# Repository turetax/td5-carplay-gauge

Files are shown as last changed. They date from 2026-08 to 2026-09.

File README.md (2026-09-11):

# TD5 CarPlay Gauge

A Raspberry Pi-based infotainment system with real-time engine monitoring and
Apple CarPlay for Land Rover Defender and Discovery 2 models powered by the
2.5-litre, five-cylinder TD5 diesel engine.

This is an independent hobby/diagnostic project. It is not affiliated with or
endorsed by JLR, Land Rover, Apple, Google, Spotify, or other trademark owners.

The TD5 dashboard is integrated directly into LIVI and runs as part of the same
full-width vehicle interface as CarPlay. Engine data is read from the TD5 ECU
through a K+DCAN cable and presented in a touch-friendly dashboard built for the
project's 1920 × 440 display.

## Features

* Live TD5 engine data inside the LIVI interface
* Apple CarPlay integration through LIVI, intended for use with a Carlinkit adapter
* A Defender-style idle dashboard with a clock, vehicle silhouette, session status,
  and live engine values whenever CarPlay is not streaming
* Coolant temperature, engine speed, voltage, fuel temperature, intake air
  temperature, MAP, calculated boost, MAF, wastegate, throttle, and injector
  balance readings
* Session peaks, trends, local history, and alert history
* Read-only ECU fault-code retrieval
* Visual warnings and an audible high-coolant-temperature alarm
* Automatic reconnection when the K+DCAN cable or ECU becomes available
* Touch-optimized interface for an in-vehicle ultra-wide display

## How it works

The system consists of two cooperating processes on the Raspberry Pi:

1. The Python TD5 gateway communicates with the ECU through `/dev/ttyUSB0`. It
   performs the TD5 diagnostic login, continuously reads engine values, and
   exposes them through a local API at `http://127.0.0.1:8080`.
2. LIVI runs as the single full-screen vehicle interface. Its built-in TD5 page
   reads the local gateway API and displays live values, history, warnings, and
   diagnostic information. LIVI also manages the CarPlay projection session. When
   the phone is disconnected, the projection area automatically becomes a compact
   vehicle overview; an active CarPlay video stream replaces it immediately.

The gateway and dashboard are read-oriented. Fault-code requests only read stored
and active faults; they do not clear codes, change ECU settings, or perform actuator
commands.

On the reference Pi, the TD5 gateway has exactly one boot entry: the desktop
user's `@reboot` cron entry. Do not additionally enable the optional systemd
gateway unit on that Pi, since two copies cannot share the local API port.

### Diagnostic architecture

The gateway is deliberately separated into a TD5 protocol layer and a small
serial transport layer. `td5_transport.py` owns adapter timing and fast init;
`td5gauge.py` owns the read-only TD5 request/decoder flow; and
`td5_signals.py` is the machine-readable catalogue of confirmed display values.
The default K-line wake-up method remains `break-condition`, which is the method
tested with this project. A `send-break` alternative is available only as an
explicit configuration choice for adapter-specific Linux testing; it is not a
general recommendation and must be verified on the vehicle first.

## Hardware

The current installation uses:

* A Raspberry Pi 4 Model B running Raspberry Pi OS
* An 11.26-inch touchscreen (1920 × 440) with an IPS panel, HDMI video input,
  and USB touch input
* A K+DCAN USB cable with an FTDI-compatible serial interface and K-line connected
  to OBD pin 7
* A Carlinkit CPC200-CCPA USB adapter for wired or wireless Apple CarPlay. The
  adapter has been purchased but has not yet arrived, so this hardware combination
  has not yet been tested in the project.

The touchscreen is detected as an ILITEK USB device and mapped to the HDMI output
by the included Wayland configuration.

### Display installation

A complete guide for installing the display in the vehicle will be added later.
It will cover physical mounting, bracket design, cable routing, dashboard fitment,
and the final in-vehicle connections. Until that guide and the power solution have
been completed and tested, the display should be treated as a bench-tested part of
the project rather than a ready-to-install vehicle kit.

### Vehicle power solution

The vehicle power solution has not yet been finalized. Work is ongoing on a safe
and reliable way to power the Raspberry Pi, display, and connected USB devices in
the vehicle.

> **Warning:** Do not connect the Raspberry Pi, display, or USB hardware directly
> to the vehicle's 12 V electrical system. These devices require properly regulated
> power, and a direct connection can permanently damage the equipment, overheat
> wiring, or create a fire risk.

A vehicle electrical system is not a clean, constant 12 V supply. Its voltage can
drop during engine cranking and rise significantly during charging or electrical
transients. The final solution therefore needs an automotive-rated DC-DC converter,
appropriate input protection, a fuse installed close to the power source, correctly
rated wiring, and sufficient output capacity for the complete system.

The power controller must also monitor the ignition state. When the ignition is
switched off, it should keep the Raspberry Pi powered long enough to complete an
orderly shutdown before disconnecting power. Cutting power immediately can corrupt
the filesystem or SD card and may prevent the system from starting correctly the
next time. Until a tested power solution is documented, this project should only be
powered from a suitable protected and regulated bench supply during testing.

### CarPlay hardware status

LIVI provides the software integration for CarPlay, but the planned Carlinkit
CPC200-CCPA dongle has not yet been connected or verified with this installation.
CarPlay support should therefore be considered untested until the adapter arrives
and has been validated on the Raspberry Pi.

## Raspberry Pi installation

Start with a fresh Raspberry Pi OS installation with the desktop, a network
connection during installation, and a supported touchscreen. Use a dedicated Pi
and SD card: this installer configures the desktop user to start the vehicle
interface automatically.

1. Flash Raspberry Pi OS (64-bit, desktop) using Raspberry Pi Imager. Create a
   normal user and enable Wi-Fi or Ethernet for the initial installation.
2. On the Pi, clone this repository and initialize the included LIVI source:

   ```sh
   git clone --recurse-submodules REPOSITORY_URL td5-carplay-gauge
   cd td5-carplay-gauge
   ```

3. Run the installer as that normal desktop user. It asks for the administrator
   password only to install packages and register the gateway service:

   ```sh
   ./scripts/install-pi.sh
   ```

4. If Node.js and `pnpm` are already installed, add `--build-livi` to build the
   integrated Td5/LIVI interface in the same step. Otherwise follow LIVI's
   documented Raspberry Pi build prerequisites, then run:

   ```sh
   ./scripts/install-pi.sh --build-livi
   ```

   For the production AppImage (preferred for the installed head unit), use:

   ```sh
   ./scripts/install-pi.sh --package-livi
   ```

   The launcher automatically prefers that package and falls back to the
   source-built Electron app when no package is present.

5. Restart the Pi. The gateway starts at boot and the full-screen dashboard is
   registered as a desktop autostart application. Connect the K+DCAN cable,
   turn the ignition to position II, and wait for the ECU state in the footer.

The installer deliberately defaults to the local-only API and read-only ECU
operations. It does not clear faults, change ECU configuration, or actuate ABS
components. Verify the wiring and software after installation with:

```sh
~/td5gauge/scripts/td5-health-check.sh
```

### First-boot configuration

`/etc/td5-gauge.conf` is created on the Pi. Normally it needs no changes: the
startup script prefers the stable `/dev/serial/by-id/...` identity of the first
USB serial adapter and only falls back to `/dev/ttyUSB0`. If several serial
adapters are connected, set the exact path in that file, then restart the
gateway:

```sh
sudo systemctl restart td5-gateway.service
```

For a production-quality kit, distribute a tested SD-card image containing the
already-built LIVI bundle. That avoids compiling Node/Electron on the buyer's
Pi and makes the above first boot genuinely flash-card, connect, and drive.

## Manual source setup

Clone the repository and enter the project directory:

```sh
git clone REPOSITORY_URL td5-carplay-gauge
cd td5-carplay-gauge
git submodule update --init
```

Create a Python virtual environment and install the TD5 gateway dependency:

```sh
python3 -m venv .venv
source .venv/bin/activate
python3 -m pip install -r requirements.txt
```

Replace `REPOSITORY_URL` with the HTTPS or SSH clone URL shown on the repository's
GitHub page. No fixed username or local installation path is required.

Apply the TD5 interface changes to the pinned LIVI source:

```sh
./scripts/apply-livi-patch.sh
```

The automated installer above is the recommended setup for a Raspberry Pi. More
detailed documentation for manual package installation, startup configuration,
display setup, and physical vehicle installation will be added as the hardware
setup is finalized.

## Runtime

For a manual or temporary test, start the TD5 gateway with:

```sh
python3 td5gauge.py --port /dev/ttyUSB0
```

The gateway keeps retrying until both the USB adapter and TD5 ECU are available.
It listens only on `127.0.0.1` by default because the API is intended for the TD5
page inside LIVI. Do not expose the diagnostic API to an untrusted network.
The installed system starts the gateway through `td5-gateway.service` and launches
the integrated LIVI interface through the desktop autostart entry installed by
`scripts/install-pi.sh`.

Boot timing markers for both processes are included in the health check:

```sh
~/td5gauge/scripts/td5-health-check.sh
```

To try the dashboard without a connected vehicle or K+DCAN cable, start it with
simulated TD5 data:

```sh
python3 td5gauge.py --simulate
```

## Roadmap

The project is currently focused on read-only diagnostics. Planned future work
includes:

* Adding carefully controlled ECU write operations
* Clearing diagnostic trouble codes from the TD5 ECU
* Supporting the ABS bleed procedure through the diagnostic interface
* Integrating a reversing camera into the LIVI interface
* Developing the vehicle power solution, including ignition-state detection and a
  controlled shutdown sequence so the Raspberry Pi can shut down safely before
  power is removed
* Publishing complete instructions for mounting and connecting the ultra-wide
  display in the vehicle

ECU write operations and ABS service procedures are safety-critical features.
They will require validated protocol support, clear user confirmation, appropriate
interlocks, and testing on compatible hardware before being enabled for general
use.

## Important

* This is not generic OBD-II. The TD5 uses its own diagnostic login and command
  flow.
* K+DCAN cables vary. OBD pin 7 must be electrically connected to K-line, and the
  USB chipset must expose a serial port.
* Never run multiple diagnostic applications against the same ECU connection.
* Disconnect the K+DCAN cable before using workshop diagnostic equipment.
* Do not use the displayed values as the sole basis for safety-critical decisions
  while driving.
* Keep Wi-Fi names, passwords, SSH keys, diagnostic profiles, and vehicle logs out
  of Git. `.env.example` documents the optional Wi-Fi variables.

## LIVI source dependency

`third_party/LIVI` is an upstream Git repository. Publish it as a pinned
submodule/fork and retain the Td5 changes as a patch or a commit in that fork;
do not publish an uncommitted nested working tree. This repository includes
`patches/livi-td5-gauge.patch`, generated against the revision recorded in
`third_party/LIVI.UPSTREAM_REVISION`. After cloning, initialize the submodule and
run `scripts/apply-livi-patch.sh` before building LIVI.

## Projects this work builds upon

* [BinOwl TD5 Gauge](https://github.com/k0sci3j/BinOwl_Td5Gauge) provides the
  foundation for the TD5 diagnostic protocol, login sequence, and command
  structure.
* [LIVI – Linux In-Vehicle Infotainment](https://github.com/f-io/LIVI) provides
  the Raspberry Pi infotainment and CarPlay platform into which the TD5 dashboard
  is integrated.

Many thanks to these projects and their contributors.

## License

This project contains a derivative port of the TD5 diagnostic command flow from
the BinOwl TD5 Gauge firmware and is distributed under
[GPL-3.0-or-later](COPYING). Refer to the upstream projects for their respective
license terms and attribution requirements.

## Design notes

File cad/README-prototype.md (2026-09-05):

# Defender EP-0189 prototype

This is a provisional fit prototype, not a final road-ready mount.

Assumptions:

- GeeekPi EP-0189 body: 276.29 x 76.50 mm (official, ±0.1 mm).
- Official viewing area: 252.69 x 57.90 mm (±0.1 mm).
- Depth remains provisional at 15 mm.
- Outer corner radius is not published; V2 uses an image-scaled estimate of
  R6.5 mm. Confirm this on the physical unit before a final print.
- Screen clearance: 0.6 mm total.
- Central rear tunnel: 198 x 70 x 62 mm, based on the published usable
  MUD-0039 face size. This is not a verified copy of its fixing geometry.
- Screen is loaded from the rear. The front lip overlaps the assumed screen
  envelope by 1 mm on every edge.
- Rear tunnel is deliberately open for cable routing and test fitting.
- The rear fixing rail has two 5.2 mm high horizontal M4 trial slots. Together
  they cover symmetric screw centre spacings from 130 to 210 mm. This is an
  intentionally adjustable test pattern, not a claimed factory dimension.

Print `ep0189_fit_coupon.stl` first. It checks the assumed screen width,
height and depth with much less material. Do not force the screen into it.

Print `defender_mount_slot_template.stl` to test the dashboard fixing centres
without printing the full housing. The template is 220 x 22 x 3 mm. Hold it
against the rear fixing points, centre it, and note the distance between the
two screw centres and their vertical offset relative to the radio opening.

The full concept housing is 284.6 x 84.6 x 81.2 mm. It may need to be split
in the slicer for printers with a bed smaller than 285 mm. Print the front
face on the bed. Use a draft profile for the first vehicle test.

The model does not yet include verified Defender screw holes, Pi standoffs,
connector cut-outs, ventilation, relay/fuse mounts or a rear service cover.
Those should be added after checking the physical screen and dashboard fit.

`defender_ep0189_one_piece_reference_fit.stl` is the preferred combined test.
It replaces the guessed slotted rail with the actual `Binnacle_Vent_Rail_v1.1`
mesh from Thingiverse design 5856588, centred and overlapped with the housing
by 0.8 mm so a slicer treats it as one part. The reference was designed and
test-fitted by mbrooker for a pre-Td5 Defender and is licensed CC BY 4.0:
https://www.thingiverse.com/thing:5856588

This reuse improves the dashboard-facing geometry, but does not prove fit in
every 1998 vehicle. The GeeekPi portion is still based on approximate published
dimensions and requires a physical fit check.

`defender_ep0189_v4_flush_one_piece.stl` places the screen's own front surface
in the same plane as the housing front. No printed bezel overlaps the screen.
The screen loads from the front and stops against a 1.2 mm rear perimeter lip.
This lip position assumes a 15 mm screen depth and must be checked physically.

To regenerate after editing the constants:

```sh
python3 cad/generate_defender_screen_prototype.py
```

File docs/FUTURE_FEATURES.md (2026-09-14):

# Framtida funktioner och återstående arbete

Den här listan sammanför projektets roadmap, nästa live-test, LIVI:s
telemetriplan och återstående arbete på den fysiska installationen. Punkter som
redan är delvis implementerade är markerade så att listan inte blandar ihop
färdig funktionalitet med återstående verifiering.

## Prioriterad arbetsordning

1. Stabil strömförsörjning utan underspänning eller strypning.
2. Komplett fordonstest med K+DCAN och TD5 ECU.
3. Verifiering och avkodning av injektorkoder.
4. CarPlay-test med riktig Carlinkit CPC200-CCPA.
5. Färdig kapsling och fordonsmontering.
6. Säkerhetskritiska ECU- och ABS-funktioner.

## TD5-diagnostik

### Nästa live-test

- Verifiera att gatewayen hittar K+DCAN via `/dev/serial/by-id`.
- Kontrollera RPM, kylvätska, laddspänning, MAP, MAF och bränsletemperatur mot
  rimliga värden med motorn igång.
- Långtidstesta anslutningen utan återanslutningar.
- Behåll `break-condition`; prova `send-break` bara vid återkommande problem och
  dokumentera kabelns USB-krets.
- Verifiera manuell, skrivskyddad DTC-avläsning i bilen.

### Injektorkoder — högsta diagnostikprioritet

- Läs ett enda skrivskyddat `21 3D`-konfigurationsblock.
- Kontrollera svarslängd, svarstyp och kontrollsumma.
- Jämför råsvaret med de fem fysiska spridarkoderna och aktuell ECU/motorkarta.
- Visa injektor 1–5 med kod och idle-nummer först efter entydig verifiering.
- Visa aldrig gissade injektorkoder.

### Säkerhetskritiska senare funktioner

- Radera TD5-felkoder.
- Skriva injektorkoder och andra ECU-inställningar.
- Eventuell immobiliseringshantering.
- ABS-luftning.
- ABS-pump-, ventil- och andra aktuatorprov.
- Kräv validerat protokoll, stillastående fordon, tydlig bekräftelse,
  säkerhetsspärrar och test på kompatibel Defender innan aktivering.

## CarPlay, Android Auto och telemetri

### CarPlay-test på riktig hårdvara

Status 2026-09-13: CPC200-CCPA är inkopplad och identifierad som `1314:1521
Magic Communication Tec. Auto Box`. LIVI har etablerat länken och visar
1174 × 440 H.264-video med Raspberry Pi:s hårdvaruavkodare och DMA-buffert.
Punkterna nedan som kräver handpåläggning återstår.

- USB-detektering och första videolänk är verifierade; långtidstesta stabiliteten.
- Testa trådbunden och trådlös CarPlay.
- Testa videostart, touch, ljud, mikrofon, Siri och ratt-/mediaknappar.
- Testa återanslutning efter urkoppling, telefonbyte, vila och omstart.
- Kontrollera att TD5-vyn återkommer direkt när CarPlay-video avslutas.

### Native CarPlay-telemetri som återstår

- Hastighet, RPM, växel, backsignal och rattvinkel.
- Blinkers, ljus, helljus, varningsblinkers och parkeringsbroms.
- Bränslenivå, förbrukning och EV-batteridata.
- Kylvätske-, olje-, insugs- och växellådstemperatur.
- Batterispänning, barometertryck, MAP, laddtryck, lambda och AFR.
- Vägmätare och trippmätare.

Nattläge, räckvidd, utomhustemperatur och GPS/GNSS är redan kopplade till
native CarPlay.

### Android Auto

- Migrera återstående AV/media-meddelanden från äldre `oaa` till
  `aap_protobuf` (`Setup`, `Config`, `Start` och `Ack`) i fas 2.

## Fordonsström och installation

- Välj fordonsklassad DC/DC-omvandlare dimensionerad för paj, skärm och USB.
- Lägg till säkring nära matningspunkten och skydd mot transienter/startfall.
- Detektera tändningsläge.
- Behåll reservkraft för en kontrollerad avstängning.
- Bryt matningen först när Raspberry Pi verkligen har stängt av.
- Testa uppstart och avstängning vid verklig motorstart.
- Eliminera rapporterad underspänning och aktiv strypning.
- Skapa en färdig, testad SD-kortsavbild för enkel installation.
- Dokumentera montering, kabeldragning och samtliga fordonsanslutningar.

Den manuella avstängningsknappen och visuell avstängningsbekräftelse är
implementerade. Automatisk avstängning från tändningssignal återstår.

## Kapsling och fysisk montering

- Verifiera skärmdjup, hörnradie, passning och skruvcentrum i bilen.
- Lägg till verifierade Defender-skruvhål.
- Lägg till Raspberry Pi-distanser och fästpunkter.
- Lägg till kontakthål, kabelgenomföringar och ventilation.
- Lägg till relä- och säkringsfästen.
- Lägg till bakre servicelucka och slutligt fäste/rem.
- Genomför temperatur-, vibrations- och slutlig passningstest.

## Teknisk skuld

- Flytta navigeringsstatus till Reacts `AppContext`.
- Ersätt direkt DOM-sökning med React-refs.
- Samordna reglerna för dold navigation.
- Ta bort äldre `label`-fält när översättningsnycklar täcker all text.
- Rätta typworkaround i FFT-worker.
- Rätta kvarvarande typfel och föråldrade testmockar.

## Delvis eller helt implementerat

- Backkamerasida och automatisk växling vid backsignal finns; fysisk kamera ska
  fortfarande verifieras.
- Säker manuell avstängning med bekräftelse finns; tändningsstyrd strömbrytning
  saknas.
- Läsning av TD5-felkoder finns; radering saknas.
- Grundläggande ABS-felkodsläsning finns; luftning och aktuatorprov saknas.
- Injektorsida finns; verifierad avkodning av injektorkoder saknas.

## Ursprungliga källor

- `README.md`, avsnitten om hårdvara, ström och roadmap.
- `docs/NEXT_LIVE_TEST.md`.
- `cad/README-prototype.md`.
- `third_party/LIVI/src/main/shared/types/Telemetry.ts`.
- `third_party/LIVI/src/main/services/telemetry/adapters/cpAdapter.ts`.
- `third_party/LIVI/src/main/services/projection/driver/aa/stack/proto/index.ts`.

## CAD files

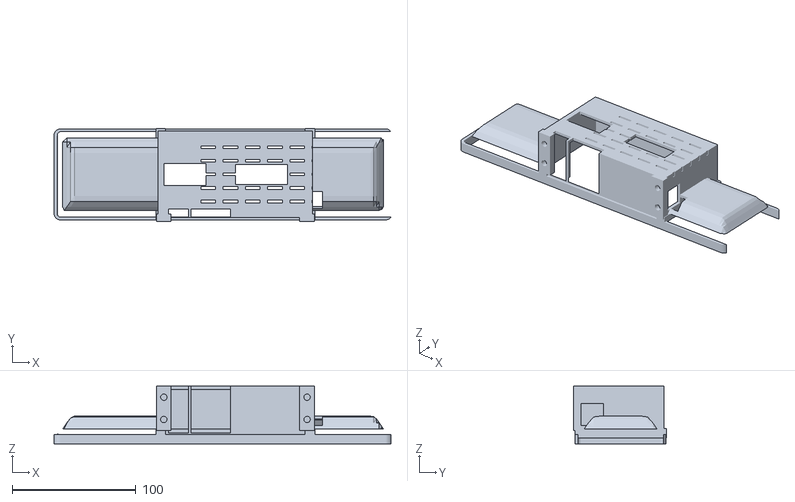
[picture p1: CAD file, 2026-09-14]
3d print/Defender_EP0189_V37_fast90_hoger_gavel_lagad_V44.stl
272.8 x 75.0 x 46.8

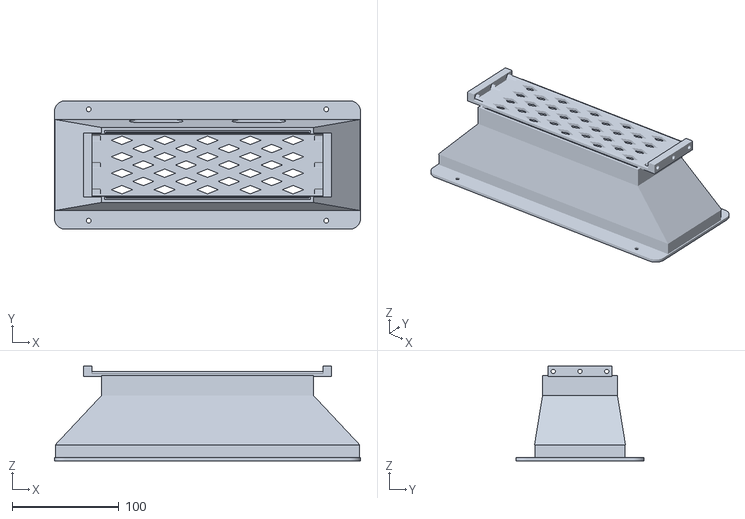
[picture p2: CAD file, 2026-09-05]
3d print/fia/Defender_EP0189_V13_plan_anliggningsyta.stl
286.0 x 120.0 x 88.7

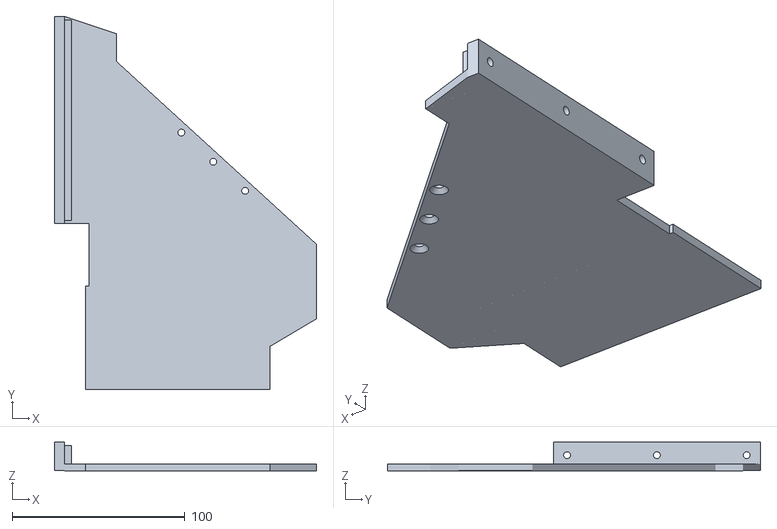
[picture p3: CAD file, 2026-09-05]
cad/reference_thingiverse_5856588/Binnacle_Side_Plate_v1.1_LH.stl
152.0 x 216.0 x 16.5

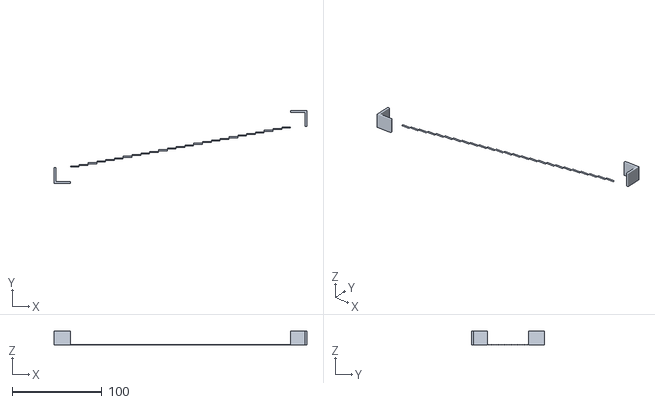
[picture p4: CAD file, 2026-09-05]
cad/stl/ep0189_fit_coupon.stl
281.3 x 81.5 x 15.6

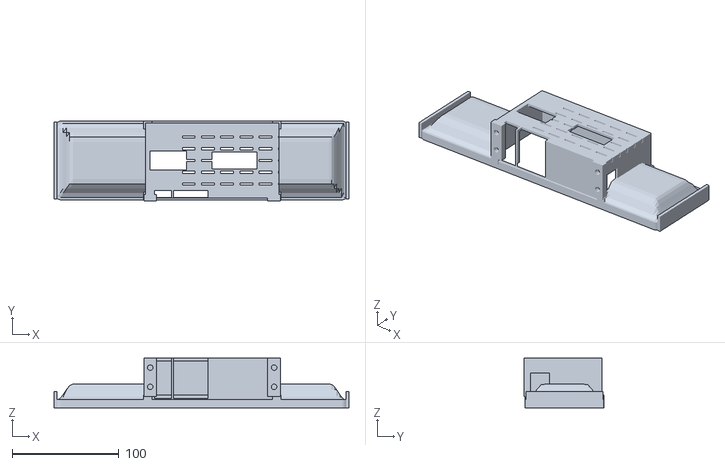
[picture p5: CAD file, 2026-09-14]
3d print/Defender_EP0189_V46_speglad_vanster_gavel_V49.stl
276.2 x 75.0 x 46.8

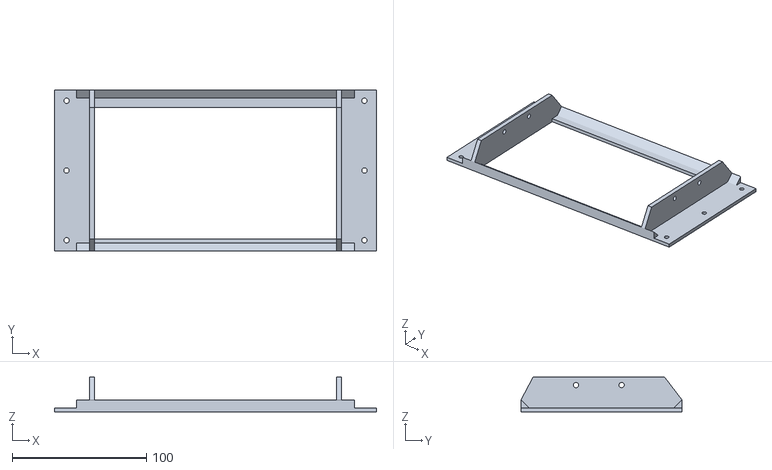
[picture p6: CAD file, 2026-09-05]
cad/reference_thingiverse_5856588/Binacle_Center_Retainer_v1.2.stl
240.0 x 120.0 x 26.0

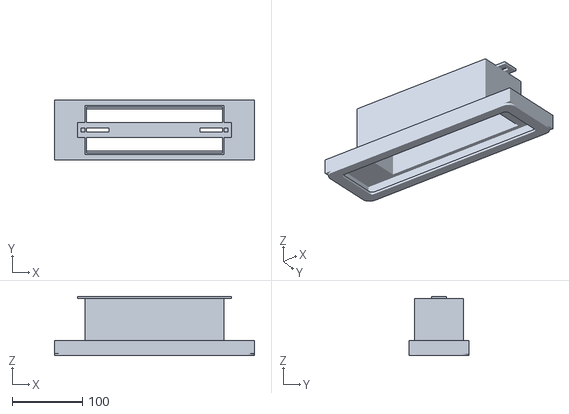
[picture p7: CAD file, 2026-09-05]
cad/stl/defender_ep0189_concept_housing.stl
284.9 x 85.1 x 84.2

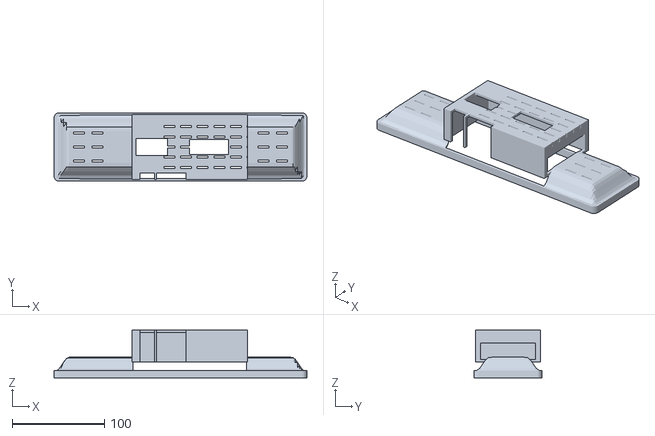
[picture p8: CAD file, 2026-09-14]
3d print/Defender_EP0189_V21_form_plus5mm_flyttade_uttag_V25.stl
273.8 x 73.8 x 51.8

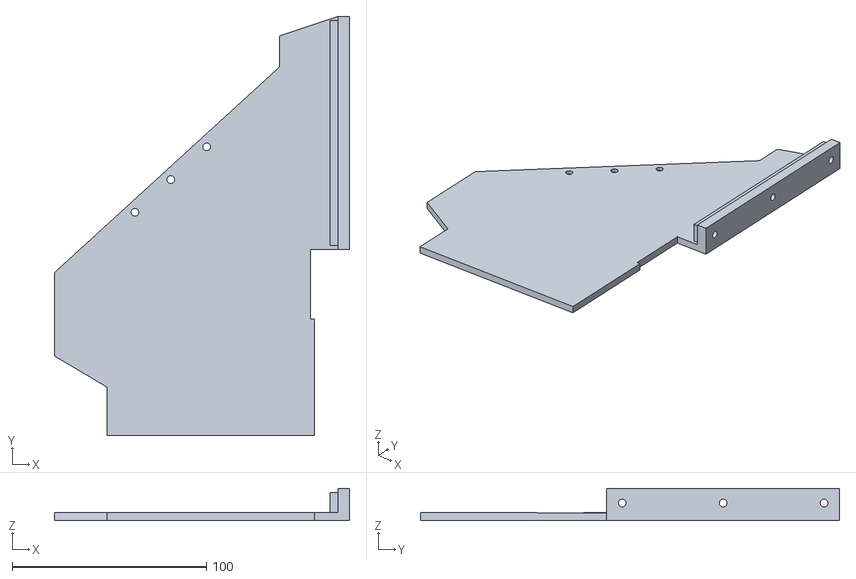
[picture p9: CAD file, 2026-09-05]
cad/reference_thingiverse_5856588/Binnacle_Side_Plate_v1.1_RH.stl
152.0 x 216.0 x 16.5

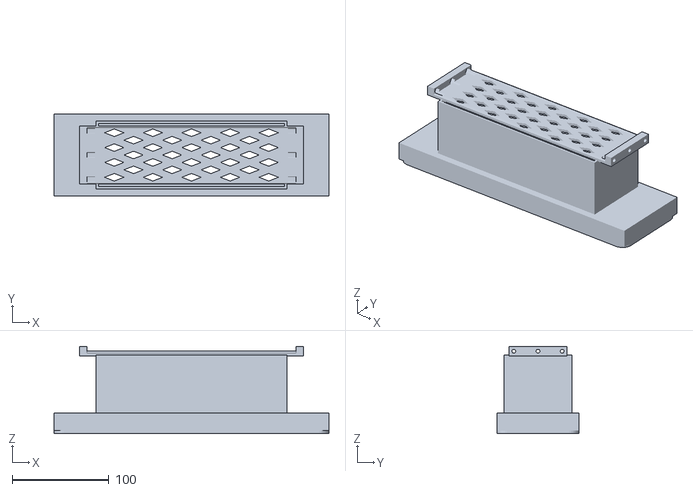
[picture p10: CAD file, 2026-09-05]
cad/stl/defender_ep0189_one_piece_reference_fit.stl
284.9 x 85.1 x 90.4

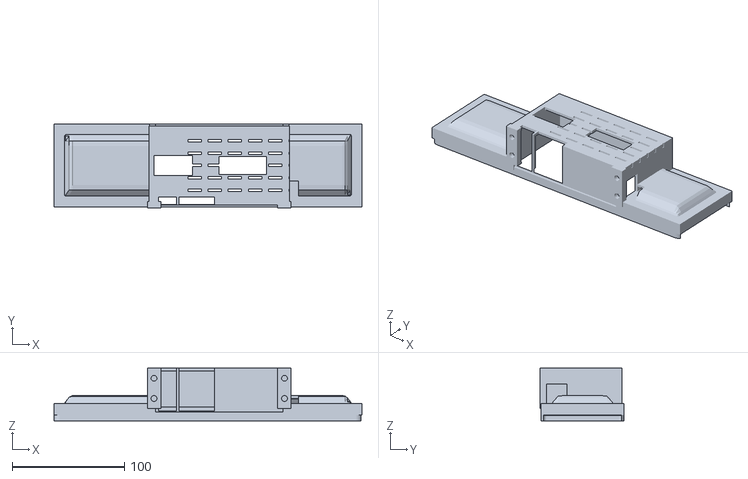
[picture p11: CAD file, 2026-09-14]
3d print/Defender_EP0189_V37_fast90_fyllda_sidobakstycken_V45.stl
273.8 x 75.0 x 46.8

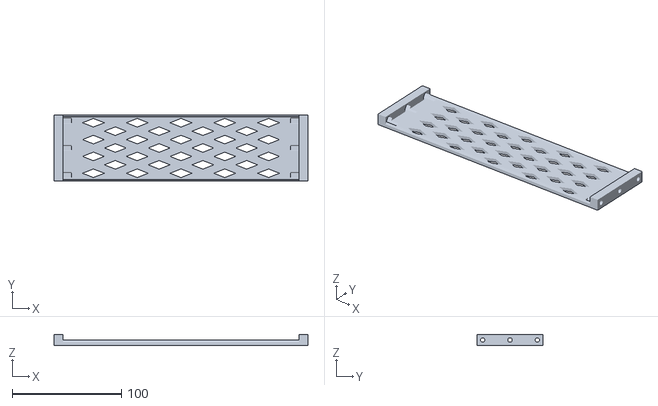
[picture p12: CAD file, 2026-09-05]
cad/reference_thingiverse_5856588/Binnacle_Vent_Rail_v1.1.stl
232.0 x 60.0 x 10.0

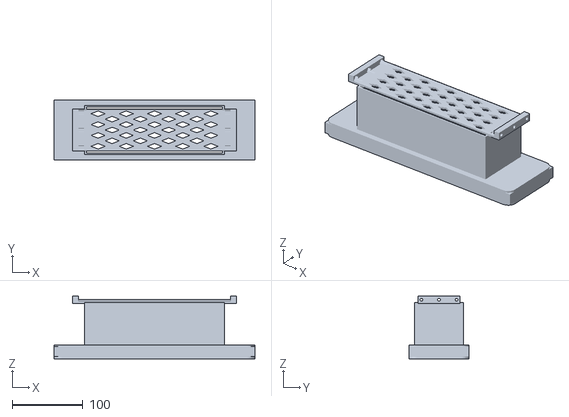
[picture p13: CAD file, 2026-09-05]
cad/stl/defender_ep0189_v4_flush_one_piece.stl
284.9 x 85.1 x 88.7

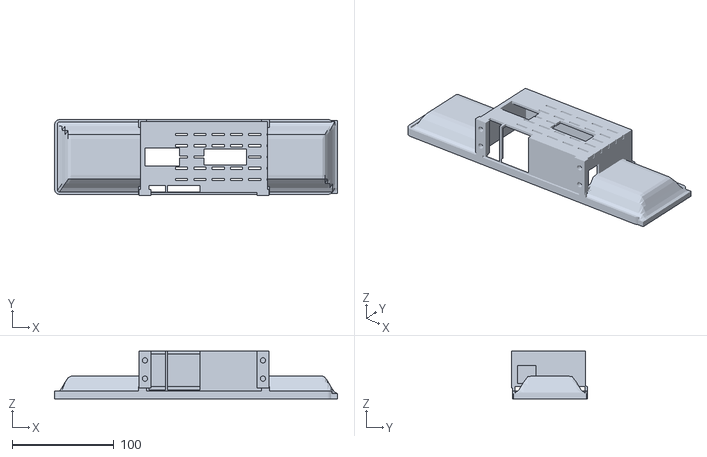
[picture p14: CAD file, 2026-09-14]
3d print/Defender_EP0189_fria_pi_gavlar_fyllda_horn_V55.stl
278.2 x 75.0 x 46.8

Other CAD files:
cad/reference_thingiverse_5856588/Binacle_Front_Plate_v1.1_Thicker_Bezle.stl
cad/stl/defender_mount_slot_template.stl
3d print/Defender_EP0189_V21_plus5mm_helt_fri_skarmvolym_V38.stl
3d print/Defender_EP0189_V21_plus5mm_bada_gavlar_fri_skarmyta_V31.stl
3d print/Defender_EP0189_V21_plus5mm_fri_skarmyta_usb_gavel_V30.stl
3d print/Defender_EP0189_V21_plus5mm_fyllda_pi_horn_V36.stl
3d print/Defender_EP0189_V21_plus5mm_fyllda_sidohal_V33.stl
3d print/Defender_EP0189_V21_plus5mm_lagade_sidohal_V32.stl
3d print/Defender_EP0189_V21_plus5mm_pibox_ansluten_V26.stl
3d print/Defender_EP0189_V21_plus5mm_pibox_utan_luft_V27.stl
3d print/Defender_EP0189_V21_plus5mm_plan_baksida_fri_volym_V39.stl
3d print/Defender_EP0189_V21_plus5mm_rensad_skarmvolym_V37.stl
3d print/Defender_EP0189_V21_plus5mm_slutna_ytterkanter_V34.stl
3d print/Defender_EP0189_V21_plus5mm_trianglar_bakom_skarm_V35.stl
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

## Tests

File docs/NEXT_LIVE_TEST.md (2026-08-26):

# Nästa live-test med K+DCAN

> **Prioritet 1 — injektorkoder:** Läs det läsande TD5-konfigurationsblocket
> (`21 3D`) och jämför råsvaret med de fem fysiska spridarkoderna. Implementera
> visning av `Injector 1–5: ABCDE · n` först när avkodningen har verifierats
> mot den aktuella ECU:n och motorkartan. Visa aldrig gissade koder.

## Förberedelser

* Bilen står stilla, växellådan i neutralläge/parkeringsläge och handbromsen är
  åtdragen.
* Anslut bara K+DCAN-kabeln till Pi:n. Kör inte parallellt Nanocom, Hawkeye,
  ELM327 eller annan diagnosutrustning på samma K-line.
* Börja med tändningen i läge II. Starta motorn endast för värden som kräver
  laddning eller varvtal.
* Spara eller fotografera de fem fysiska koderna från spridarna, i cylinderordning
  1–5. Notera även vilken mapp/ECU-typ bilen använder om det är känt.

## Testordning

1. **Adapter och session:** kontrollera att gatewayen hittar adaptern via
   `/dev/serial/by-id` och att status blir `Ansluten` med tändningen i läge II.
   Spara det användarvänliga felmeddelandet om den inte ansluter.
2. **Injektorkonfiguration — läsande test:** hämta ett enda `21 3D`-svar,
   spara råsvaret lokalt och kontrollera längd, svarstyp och kontrollsumma.
   Inga inställningar får skrivas och inga koder får rensas.
3. **Verifiera avkodning:** jämför blocket med de kända spridarkoderna. Först
   efter en entydig matchning läggs kod och idle-nummer in på injektorsidan.
4. **Livevärden med motor igång:** jämför RPM, kylvätska, laddspänning, MAP,
   MAF och bränsletemperatur mot rimliga värden. Kontrollera att kabeln klarar
   minst några minuter utan återanslutningar.
5. **K-line timing endast vid problem:** behåll `break-condition` om allt
   fungerar. Testa det alternativa `send-break`-läget endast om anslutningen
   återkommande misslyckas och dokumentera vilket kabelchip som används.
6. **Felkoder:** gör en manuell, läsande DTC-avläsning och kontrollera att
   dashboarden visar tydlig status. Rensa inga felkoder under detta test.

## Utanför scope tills vidare

* ABS-luftning, ABS-pump/ventiler och andra aktuatorprov.
* Skrivning av injektorkoder, ECU-inställningar eller immobiliserdata.
* Felkodsrensning.

De funktionerna kräver Defender-specifik protokollvalidering och separat,
tydlig användarbekräftelse.

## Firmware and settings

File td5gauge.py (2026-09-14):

#!/usr/bin/env python3
"""Read-only TD5 K-line gateway for LIVI and a raw K+DCAN serial adapter."""

from __future__ import annotations

import argparse
import csv
import json
import math
import os
import threading
import time
from collections import deque
from datetime import datetime
from urllib.parse import urlsplit
from dataclasses import asdict, dataclass
from http import HTTPStatus
from http.server import BaseHTTPRequestHandler, ThreadingHTTPServer
from pathlib import Path

try:
    from serial.tools import list_ports
except ImportError:  # Helpful error when launched before installation.
    list_ports = None

from td5_signals import SIGNALS
from td5_transport import SerialTransport


BAUDRATE = 10_400
LOG_RETENTION_DAYS = 7
LOG_MAX_BYTES = 25 * 1024 * 1024
PROFILE_RETENTION_COUNT = 10
CRITICAL_ALERT_LATCH_SECONDS = 8
FUEL_DENSITY_KG_PER_L = 0.832
FUEL_WINDOW_TARGET_KM = 100.0
FUEL_WINDOW_RETAIN_KM = 120.0
LIVE_FIELDS = (
    "rpm", "speed_kmh", "voltage_v", "coolant_c", "air_c", "fuel_c",
    "map_kpa", "aap_kpa", "maf_kg_h", "wastegate_percent", "throttle_1",
    "throttle_2", "throttle_3", "throttle_supply_v", "ecu_variant", "driver_fuel_demand_mg",
    "fuel_injected_mg", "idle_fuel_demand_mg", "injector_balance",
)


@dataclass
class GaugeData:
    status: str = "Inte ansluten"
    detail: str = "Väntar på K-line-adapter"
    updated_at: float = 0.0
    rpm: int | None = None
    speed_kmh: int | None = None
    voltage_v: float | None = None
    coolant_c: float | None = None
    air_c: float | None = None
    fuel_c: float | None = None
    map_kpa: float | None = None
    aap_kpa: float | None = None
    maf_kg_h: float | None = None
    wastegate_percent: float | None = None
    throttle_1: float | None = None
    throttle_2: float | None = None
    throttle_3: float | None = None
    throttle_supply_v: float | None = None
    ecu_variant: str | None = None
    driver_fuel_demand_mg: float | None = None
    fuel_injected_mg: float | None = None
    idle_fuel_demand_mg: float | None = None
    injector_balance: list[float] | None = None


class Td5Protocol:
    """Td5 K-line protocol ported from BinOwl's published GPL-3.0 firmware."""

    # name: (request bytes, response byte count, ECU response delay in milliseconds)
    COMMANDS = {
        "init": (bytes((0x81, 0x13, 0xF7, 0x81)), 5, 35),
        "diagnostic": (bytes((0x02, 0x10, 0xA0)), 3, 35),
        "seed": (bytes((0x02, 0x27, 0x01)), 6, 50),
        "rpm": (bytes((0x02, 0x21, 0x09)), 6, 50),
        "voltage": (bytes((0x02, 0x21, 0x10)), 8, 50),
        "temps": (bytes((0x02, 0x21, 0x1A)), 20, 100),
        "speed": (bytes((0x02, 0x21, 0x0D)), 5, 50),
        "fuel": (bytes((0x02, 0x21, 0x1D)), 22, 100),
        "pressure": (bytes((0x02, 0x21, 0x23)), 8, 50),
        "maf_map": (bytes((0x02, 0x21, 0x1C)), 12, 50),
        "injectors": (bytes((0x02, 0x21, 0x40)), 14, 50),
        "throttle_msb": (bytes((0x02, 0x21, 0x1B)), 12, 50),
        "throttle_nnn": (bytes((0x02, 0x21, 0x1B)), 14, 50),
        "wastegate": (bytes((0x02, 0x21, 0x38)), 6, 50),
        "keep_alive": (bytes((0x02, 0x3E, 0x01)), 3, 30),
    }

    def __init__(
        self,
        port: str,
        fast_init_mode: str = "break-condition",
        transport: SerialTransport | None = None,
    ):
        # timeout is deliberately short: each Td5 transaction has a known reply length.
        self.transport = transport or SerialTransport(port, BAUDRATE)
        self.fast_init_mode = fast_init_mode
        self.nnn = False

    def close(self) -> None:
        self.transport.close()

    def fast_init(self) -> None:
        """Drive K-line low/high: 25 ms each, as required by Td5 fast init.

        This only works if the adapter's TX pin is physically connected to K-line.
        Some K+DCAN cables do not satisfy that requirement.
        """
        self.transport.fast_init(self.fast_init_mode)

    @staticmethod
    def checksum(payload: bytes) -> int:
        return sum(payload) & 0xFF

    @staticmethod
    def keygen(seed_response: bytes) -> int:
        q = seed_response[4] | (seed_response[3] << 8)
        cycles = (((q >> 12) & 0x8) | ((q >> 5) & 0x4) | ((q >> 3) & 0x2) | (q & 0x1)) + 1
        for _ in range(cycles):
            bit = ((q >> 1) ^ (q >> 2) ^ (q >> 8) ^ (q >> 9)) & 1
            shifted = (q >> 1) | (bit << 15)
            q = shifted & ~1 if ((q >> 3) & 1 and (q >> 13) & 1) else shifted | 1
        return q

    def transact(self, name: str, request_override: bytes | None = None) -> bytes:
        request, response_length, response_delay_ms = self.COMMANDS[name]
        if request_override is not None:
            request = request_override
        frame = request + bytes((self.checksum(request),))
        self.transport.reset_input()
        for byte in frame:
            self.transport.write_byte(byte)
            time.sleep(0.003)  # Td5 requires inter-byte pacing.
        time.sleep(response_delay_ms / 1000)

        # USB K+DCAN adapters commonly echo TX. Some do not, so preserve both cases.
        deadline = time.monotonic() + 0.15
        raw = bytearray()
        expected_total = len(frame) + response_length
        while time.monotonic() < deadline and len(raw) < expected_total:
            received = self.transport.read(expected_total - len(raw))
            if received:
                raw.extend(received)
            else:
                time.sleep(0.002)
        response = bytes(raw[len(frame):]) if raw.startswith(frame) else bytes(raw)
        # Td5 key-access acknowledgement is a special four-byte positive response
        # (04 67 01 00) on NNN ECUs; unlike the measurement frames it does not carry
        # the additive checksum used by the rest of this protocol.
        valid_key_ack = name == "key" and response == bytes((0x04, 0x67, 0x01, 0x00))
        if len(response) != response_length or not response or (not valid_key_ack and self.checksum(response[:-1]) != response[-1]):
            raise RuntimeError(f"{name}: ogiltigt svar ({raw.hex(' ') or 'inget svar'})")
        return response

    def transact_variable(self, name: str, request: bytes, response_delay_ms: int = 100) -> bytes:
        """Read a complete ECU-framed response whose payload length is supplied by the ECU.

        This is deliberately limited to read-only commands.  The first byte of a
        KWP response declares its data length, so an incomplete or checksum-bad
        response is rejected rather than being partially decoded.
        """
        frame = request + bytes((self.checksum(request),))
        self.transport.reset_input()
        for byte in frame:
            self.transport.write_byte(byte)
            time.sleep(0.003)
        time.sleep(response_delay_ms / 1000)
        raw = bytearray()
        deadline = time.monotonic() + 0.5
        while time.monotonic() < deadline:
            received = self.transport.read(64)
            if received:
                raw.extend(received)
            else:
                time.sleep(0.002)
            starts = (len(frame),) if raw.startswith(frame) else (0,)
            for start in starts:
                if len(raw) <= start:
                    continue
                length = raw[start] & 0x7F
                has_addresses = bool(raw[start] & 0x80)
                if not 1 <= length <= 48:
                    continue
                total = 1 + (2 if has_addresses else 0) + length + 1
                if len(raw) < start + total:
                    continue
                response = bytes(raw[start:start + total])
                if self.checksum(response[:-1]) == response[-1]:
                    return response
                raise RuntimeError(f"{name}: kontrollsumma fel ({raw.hex(' ')})")
        raise RuntimeError(f"{name}: inget komplett svar ({raw.hex(' ') or 'inget svar'})")

    def read_faults(self) -> tuple[list[dict], str]:
        """Read Td5 local identifier 0x20.  This request never clears or changes ECU data."""
        response = self.transact_variable("felkoder", bytes((0x02, 0x21, 0x20)))
        if len(response) < 4 or response[1:3] != bytes((0x61, 0x20)):
            raise RuntimeError(f"felkoder: oväntat svar ({response.hex(' ')})")
        payload = response[3:-1]
        if len(payload) % 2:
            raise RuntimeError(f"felkoder: ogiltig datalängd ({response.hex(' ')})")
        output_names = ("EGR-spjäll", "Wastegate", "EGR-vakuum", "Temperaturmätare", "Gaspedal 1", "Gaspedal 2", "MAF-krets", "MAP-krets")
        sensor_names = ("Insugslufttemperatur", "Bränsletemperatur", "Kylvätsketemperatur", "Batterispänning", "Referensspänning", "Omgivningstemperatur", "Gaspedal-matning", "Atmosfärtryck")
        faults: list[dict] = []
        for index, counter in zip(payload[::2], payload[1::2]):
            if index == 0 and counter == 0:
                continue
            group, sub = index // 8 + 1, index % 8 + 1
            if group in (1, 3, 5):
                description = output_names[sub - 1]
            elif group in (2, 4, 6):
                description = sensor_names[sub - 1]
            else:
                description = "Okänd Td5-funktionsgrupp"
            state = "AKTIV" if group in (5, 6) else "LAGRAD"
            faults.append({"code": f"{group}-{sub}", "state": state, "description": description, "counter": counter})
        return faults, payload.hex(" ").upper()

    def read_feature_configuration(self) -> str:
        """Read the Td5 0x3D feature/configuration block without changing settings.

        `21 3D` is not an established injector-code read. Store its raw bytes as
        ECU feature configuration until each flag has been mapped by differential
        testing. This must never be presented as injector classification data.
        """
        response = self.transact_variable("funktionskonfiguration", bytes((0x02, 0x21, 0x3D)))
        if len(response) < 4 or response[1:3] != bytes((0x61, 0x3D)):
            raise RuntimeError(f"funktionskonfiguration: oväntat svar ({response.hex(' ')})")
        return response[3:-1].hex(" ").upper()

    def connect(self) -> None:
        self.fast_init()
        self.transact("init")
        self.transact("diagnostic")
        seed = self.transact("seed")
        key = self.keygen(seed)
        key_request = bytes((0x04, 0x27, 0x02, key >> 8, key & 0xFF))
        # The key response is 4 bytes long, but request differs from the stored commands.
        self.COMMANDS["key"] = (key_request, 4, 50)
        self.transact("key")

    @staticmethod
    def u16(response: bytes, offset: int) -> int:
        return response[offset] | (response[offset - 1] << 8)

    @staticmethod
    def s16(response: bytes, offset: int) -> int:
        value = Td5Protocol.u16(response, offset)
        return value - 65536 if value >= 32768 else value

    def poll(self, data: GaugeData) -> None:
        rpm = self.transact("rpm")
        data.rpm = self.u16(rpm, 4)
        voltage = self.transact("voltage")
        data.voltage_v = ((voltage[6] | (voltage[5] << 8) | voltage[7]) / 1000)
        temps = self.transact("temps")
        data.coolant_c = self.s16(temps, 4) / 10 - 273
        data.air_c = self.s16(temps, 8) / 10 - 273
        data.fuel_c = self.s16(temps, 16) / 10 - 273
        speed = self.transact("speed")
        data.speed_kmh = speed[3]
        fuel = self.transact("fuel")
        data.driver_fuel_demand_mg = self.s16(fuel, 4) / 100
        data.fuel_injected_mg = self.s16(fuel, 10) / 100
        data.idle_fuel_demand_mg = self.s16(fuel, 18) / 100
        pressure = self.transact("pressure")
        data.map_kpa = self.u16(pressure, 4) / 100
        data.aap_kpa = self.u16(pressure, 6) / 100
        maf_map = self.transact("maf_map")
        data.maf_kg_h = self.u16(maf_map, 8) / 10
        injectors = self.transact("injectors")
        data.injector_balance = [self.s16(injectors, pos) for pos in (4, 6, 8, 10, 12)]
        throttle_name = "throttle_nnn" if self.nnn else "throttle_msb"
        try:
            throttle = self.transact(throttle_name)
        except RuntimeError:
            self.nnn = not self.nnn
            throttle = self.transact("throttle_nnn" if self.nnn else "throttle_msb")
        data.throttle_1 = self.u16(throttle, 4) / 1000
        data.throttle_2 = self.u16(throttle, 6) / 1000
        if self.nnn and len(throttle) >= 12:
            data.throttle_3 = self.u16(throttle, 8) / 1000
            data.throttle_supply_v = self.u16(throttle, 12) / 1000
        else:
            data.throttle_3 = None
            data.throttle_supply_v = None
        # The 14-byte NNN pedal response contains track 3 and its 5 V supply;
        # the shorter MSB frame does not. This identifies the diagnostic family,
        # not an ECU part number or serial number.
        data.ecu_variant = "NNN" if self.nnn else "MSB"
        wastegate = self.transact("wastegate")
        data.wastegate_percent = self.u16(wastegate, 4) / 1000
        self.transact("keep_alive")


class WabcoDProtocol(Td5Protocol):
    """Read-only WABCO D ABS diagnostic profile.

    The profile is based on the published Discovery 2 SLABS capture: fast-init
    address 0x29 followed by local identifiers 0x11 (stored) and 0x47
    (current).  Defender 1999--2003 and Discovery 2 use the WABCO D family,
    but this class deliberately exposes *only* read requests.  No clear,
    routine, pump, valve, or bleed command exists here.
    """

    TARGET_ADDRESS = 0x29
    TESTER_ADDRESS = 0xF1
    # discovery2-diag's verified WABCO D capture uses the functional fast-init
    # form first (C1 29 F1 81). The physical F7 form did not answer on this
    # Defender, so do not keep re-sending it as the default.
    INIT_REQUEST = bytes((0xC1, TARGET_ADDRESS, TESTER_ADDRESS, 0x81))
    SESSION_CONFIRM = bytes((0x02, 0x1A, 0x8A))
    STORED_FAULTS = bytes((0x02, 0x21, 0x11))
    CURRENT_FAULTS = bytes((0x02, 0x21, 0x47))

    # Two anchor points are confirmed by the capture used by discovery2-diag.
    # Any other bit is kept as an exact raw position instead of being guessed.
    KNOWN_FAULT_BITS = {
        (3, 4): ("020", "Höger främre hjulhastighetssensor · signal för låg"),
        (10, 4): ("027", "Shuttle valve switch · elektriskt fel"),
    }

    def _raw_request(self, name: str, request: bytes, *, delay_ms: int = 100) -> bytes:
        """Send one checksummed KWP frame and return the full reply burst.

        Fast-init's C1 reply is intentionally checked as a presence marker;
        cheap K-line adapters can damage its checksum.  The two fault blocks
        below still go through :meth:`transact_variable` and must have a valid
        KWP checksum before they are decoded.
        """
        frame = request + bytes((self.checksum(request),))
        self.transport.reset_input()
        for byte in frame:
            self.transport.write_byte(byte)
            time.sleep(0.005)
        time.sleep(delay_ms / 1000)
        raw = bytearray()
        deadline = time.monotonic() + 0.45
        while time.monotonic() < deadline:
            received = self.transport.read(64)
            if received:
                raw.extend(received)
            elif raw:
                break
            else:
                time.sleep(0.002)
        reply = bytes(raw[len(frame):]) if raw.startswith(frame) else bytes(raw)
        if not reply:
            raise RuntimeError(f"{name}: inget svar")
        return reply

    def connect(self) -> None:
        self.fast_init()
        reply = self._raw_request("ABS init", self.INIT_REQUEST, delay_ms=80)
        # The proven WABCO D/SLABS init responds with a C1 start-communication
        # marker.  Do not interpret any other byte sequence as an ABS session.
        if 0xC1 not in reply:
            raise RuntimeError(f"ABS init: oväntat svar ({reply.hex(' ')})")
        confirmation = self.transact_variable("ABS sessionbekräftelse", self.SESSION_CONFIRM, 150)
        if len(confirmation) < 3 or confirmation[1:3] != bytes((0x5A, 0x8A)):
            raise RuntimeError(f"ABS sessionbekräftelse: oväntat svar ({confirmation.hex(' ')})")

    @classmethod
    def decode_fault_block(cls, block: bytes) -> list[dict]:
        faults: list[dict] = []
        for byte_index, value in enumerate(block[:16]):
            for bit in range(8):
                if not value & (1 << bit):
                    continue
                code, description = cls.KNOWN_FAULT_BITS.get(
                    (byte_index, bit),
                    (f"BIT-{byte_index + 1:02d}-{bit + 1:02d}", "Okänd WABCO D-felkodsbit"),
                )
                faults.append({"code": code, "description": description, "byte": byte_index, "bit": bit})
        return faults

    def read_faults(self) -> dict:
        stored = self.transact_variable("ABS lagrade felkoder", self.STORED_FAULTS, 100)
        current = self.transact_variable("ABS aktiva felkoder", self.CURRENT_FAULTS, 100)
        def block(response: bytes, lid: int) -> bytes:
            if len(response) < 4 or response[1:3] != bytes((0x61, lid)):
                raise RuntimeError(f"ABS felkoder {lid:02X}: oväntat svar ({response.hex(' ')})")
            payload = response[3:-1]
            if len(payload) < 16:
                raise RuntimeError(f"ABS felkoder {lid:02X}: för kort svar ({response.hex(' ')})")
            return payload[:16]
        stored_block, current_block = block(stored, 0x11), block(current, 0x47)
        return {
            "stored": self.decode_fault_block(stored_block),
            "current": self.decode_fault_block(current_block),
            "stored_raw": stored_block.hex(" ").upper(),
            "current_raw": current_block.hex(" ").upper(),
        }
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

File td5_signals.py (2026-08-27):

"""Machine-readable metadata for values confirmed in the TD5 dashboard."""

from __future__ import annotations

from typing import Final

# Values not in this catalogue must be shown as unavailable, never invented.
SIGNALS: Final[dict[str, dict[str, str]]] = {
    "rpm": {"label": "Engine speed", "unit": "RPM", "confidence": "verified"},
    "speed_kmh": {"label": "Vehicle speed", "unit": "km/h", "confidence": "verified"},
    "voltage_v": {"label": "Alternator", "unit": "V", "confidence": "verified"},
    "coolant_c": {"label": "Coolant", "unit": "°C", "confidence": "verified"},
    "air_c": {"label": "Inlet air", "unit": "°C", "confidence": "verified"},
    "fuel_c": {"label": "Fuel temp", "unit": "°C", "confidence": "verified"},
    "map_kpa": {"label": "MAP", "unit": "kPa", "confidence": "verified"},
    "aap_kpa": {"label": "Ambient pressure", "unit": "kPa", "confidence": "verified"},
    "maf_kg_h": {"label": "MAF", "unit": "kg/h", "confidence": "verified"},
    "wastegate_percent": {"label": "Wastegate", "unit": "%", "confidence": "verified"},
    "throttle_1": {"label": "Throttle 1", "unit": "V", "confidence": "verified"},
    "throttle_2": {"label": "Throttle 2", "unit": "V", "confidence": "verified"},
    "throttle_3": {"label": "Throttle 3", "unit": "V", "confidence": "verified when fitted"},
    "throttle_supply_v": {"label": "Throttle supply", "unit": "V", "confidence": "verified when available"},
    "driver_fuel_demand_mg": {"label": "Driver fuel demand", "unit": "mg/stroke", "confidence": "BinOwl reference; pending vehicle validation"},
    "fuel_injected_mg": {"label": "Fuel injected", "unit": "mg/stroke", "confidence": "BinOwl reference; pending vehicle validation"},
    "idle_fuel_demand_mg": {"label": "Idle fuel demand", "unit": "mg/stroke", "confidence": "BinOwl reference; pending vehicle validation"},
    "injector_balance": {"label": "Injector balance", "unit": "", "confidence": "verified"},
}

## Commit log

2026-08-25 Add Raspberry Pi installation workflow
2026-08-27 Correct TD5 3D feature block classification
    [td5gauge.py]
2026-09-05 checkpoint: save project before idle dashboard
    [Binacle_Center_Retainer_v1.2.stl, Binacle_Front_Plate_v1.1_Thicker_Bezle.stl, Binnacle_Side_Plate_v1.1_LH.stl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]
2026-09-14 Harden deployment and complete TD5 integration
    [Defender_EP0189_V21_form_plus5mm_flyttade_uttag_V25.stl, Defender_EP0189_V21_plus5mm_bada_gavlar_fri_skarmyta_V31.stl, Defender_EP0189_V21_plus5mm_fri_skarmyta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]
2026-10-02 Harden Raspberry Pi deployment startup
